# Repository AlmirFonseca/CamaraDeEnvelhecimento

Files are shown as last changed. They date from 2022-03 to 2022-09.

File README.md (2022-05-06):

# Câmara de Envelhecimento
Repositório de manutenção da câmara de envelhecimento, construído para o Dep. Eng. Civil da Universidade Federal de Viçosa.

## Módulos
A Câmara dispõe de diversos módulos, os quais estão representados nos <a href=“https://github.com/AlmirFonseca/CamaraDeEnvelhecimento/tree/main/Diagramas%20de%20montagem“>diagramas de montagem</a> e estão listados abaixo:
                
+ Arduino MEGA 2560
+ Sensor de Temperatura  DS18B20 (I e II)
+ Sensor de Umidade DHT22
+ Sensor de Irradiância UV ML8511
+ RTC DS3231
+ Módulo de Cartão Micro SD
+ Módulo de Relé (de 1 e 2 canais)
+ Rotary Encoder KY-040
+ Display LCD 16x2
+ Fonte de alimentação MB102
                
----

## Manutenção
Para a maioria dos casos de mau funcionamento da parte eletrônica da câmara, seguem as seguintes instruções:

1. Verificar se, ao incializar o dispositivo, alguma mensagem de erro é exibida no display LCD. Caso algum erro seja relatado, siga as orientações descritas na tela.
2. Confira as conexões do módulo que apresenta mau funcionamento, verificando se não há algum cabo solto no interior da caixa, ou se está apenas mal conectado
3. Para alguns casos, existem considerações especiais:
	3.1. No caso de mau funcionamento do relógio (RTC DS3231) confira as conexões caso a data seja "165/165/2165", e confira o estado da bateria (CR2032) caso a data seja algo como "01/01/2000".
	3.2. Caso ocorram erros no arquivamento dos arquivos no cartão de memória, é recomendado retirá-lo e formatá-lo o cartão com o auxílio do [SD Card Formatter](https://www.sdcard.org/downloads/formatter/), utilizando a configuração "Overwrite format" (ATENÇÃO, pois isso apagará todos os dados existentes na memória do cartão).
4. Caso nenhum dos procedimentos acima tenha surtido efeito, é recomendado avaliar a integridade do componente que apresenta mau funcionamento, seja a partir de um outro código para o Arduino, ou seja substituindo esse componente por um similar. Todos os componentes podem ser substituídos, sem serem necessárias alterações no código-fonte do Arduino.
                
----

## Conexões
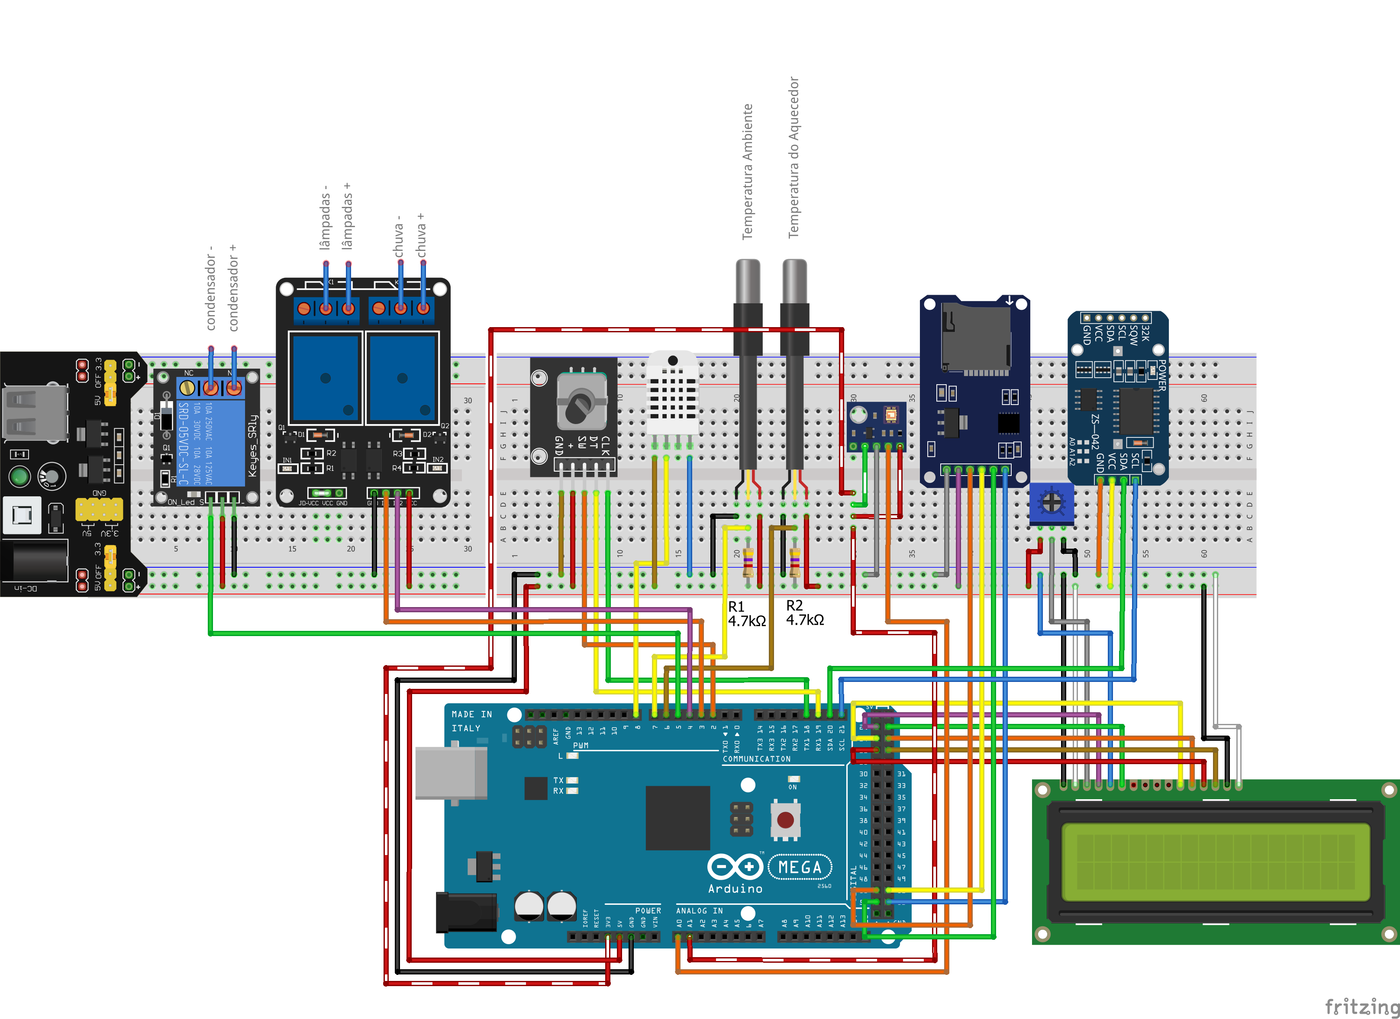
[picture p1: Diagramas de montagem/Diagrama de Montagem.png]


+ Sensor de Temperatura  DS18B20 (I e II):
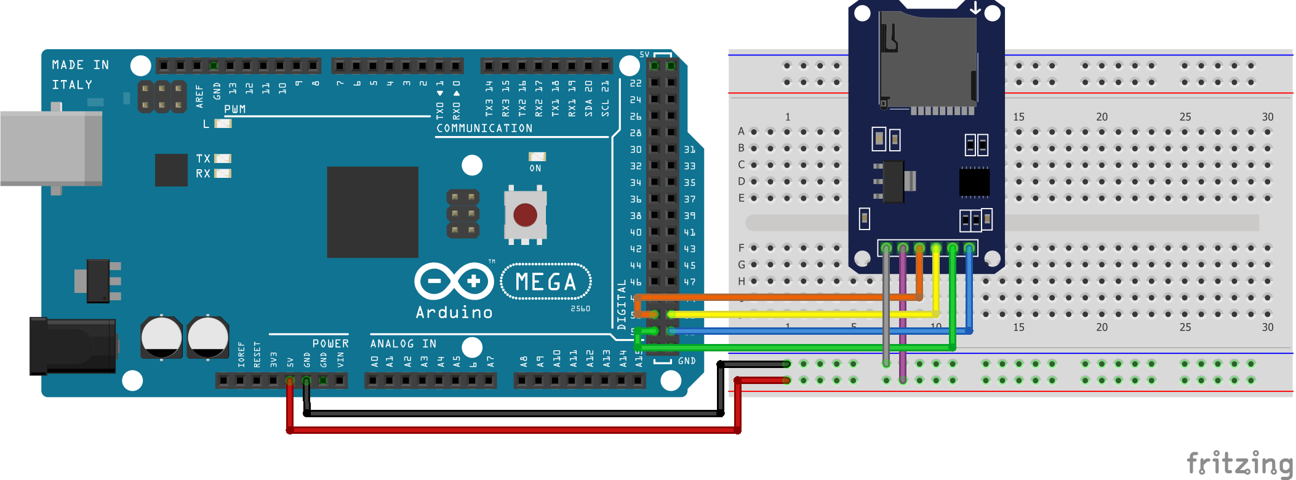
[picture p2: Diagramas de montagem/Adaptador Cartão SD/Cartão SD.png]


+ Sensor de Umidade DHT22:
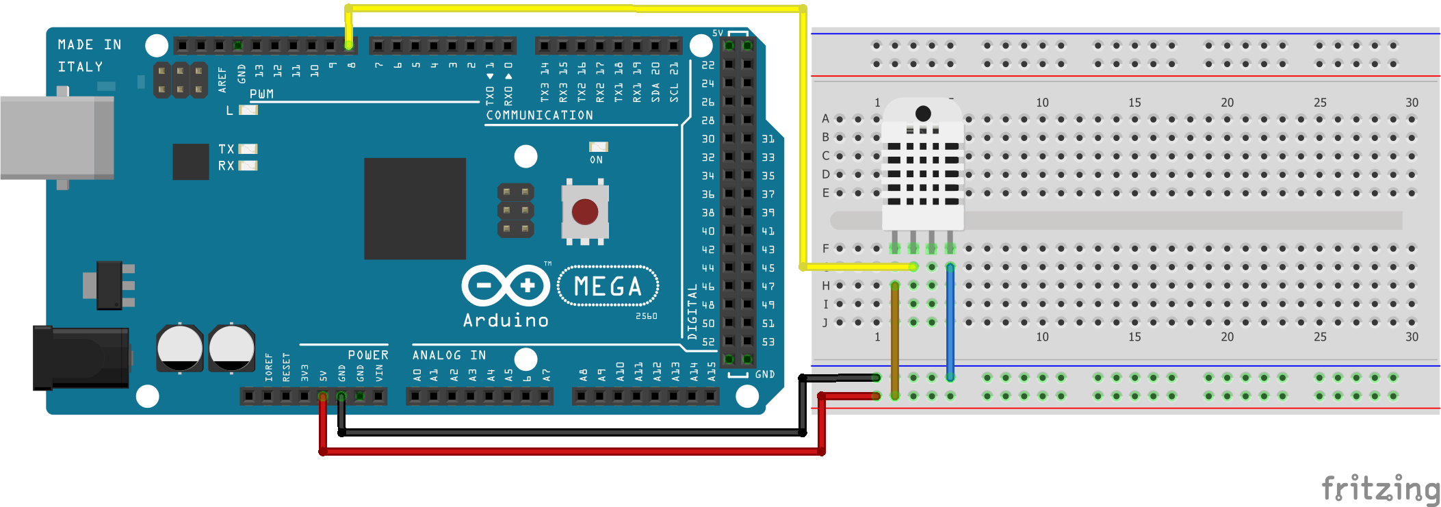
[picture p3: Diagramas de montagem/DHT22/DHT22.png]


+ Sensor de Irradiância UV ML8511:
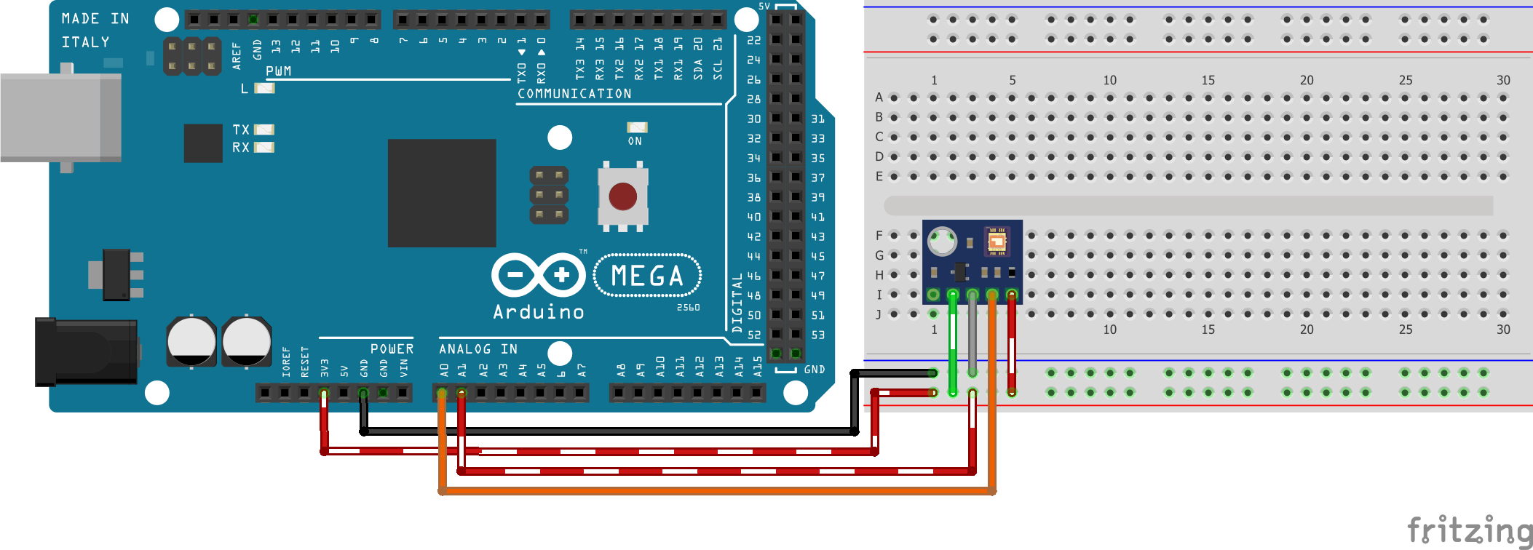
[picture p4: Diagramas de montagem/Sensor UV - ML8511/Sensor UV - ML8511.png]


+ RTC DS3231:
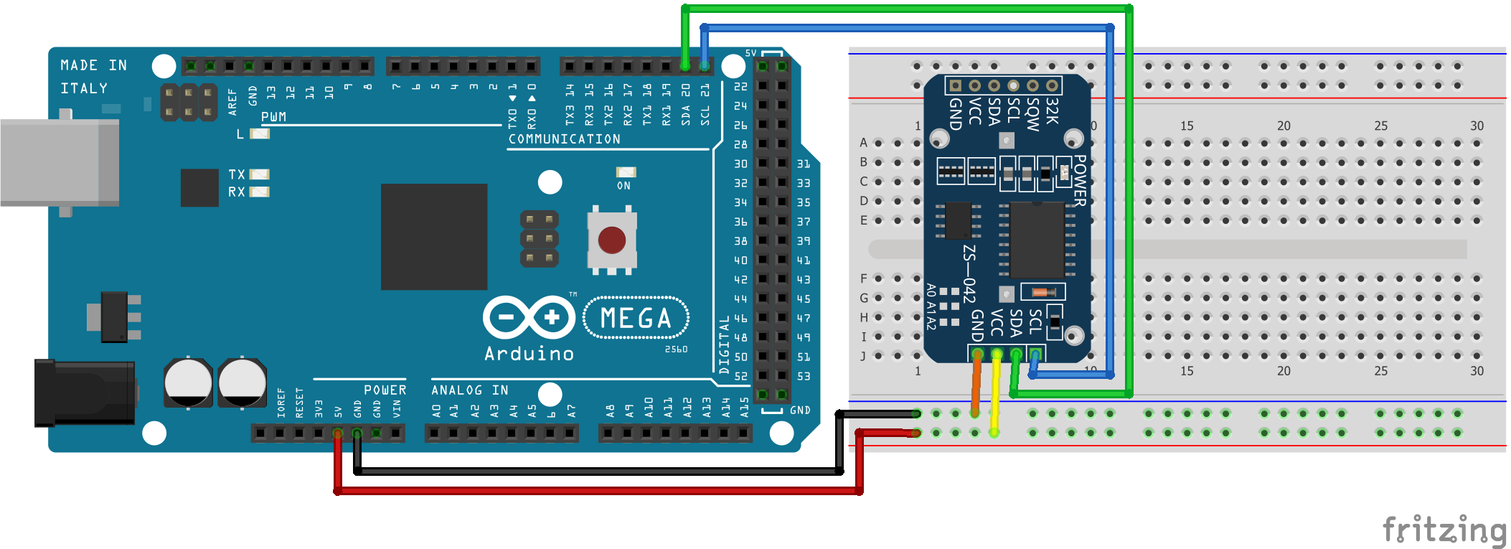
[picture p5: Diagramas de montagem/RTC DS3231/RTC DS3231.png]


+ Módulo de Cartão Micro SD:


+ Rotary Encoder KY-040:
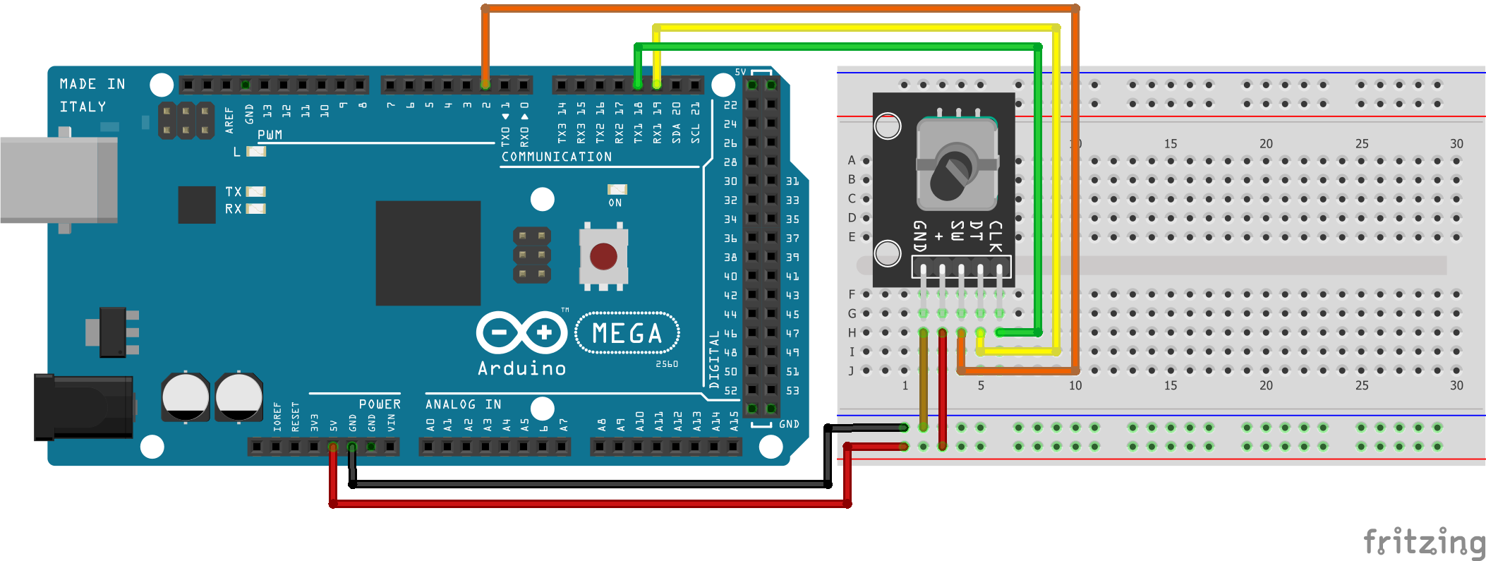
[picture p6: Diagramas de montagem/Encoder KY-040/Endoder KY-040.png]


+ Display LCD 16x2:
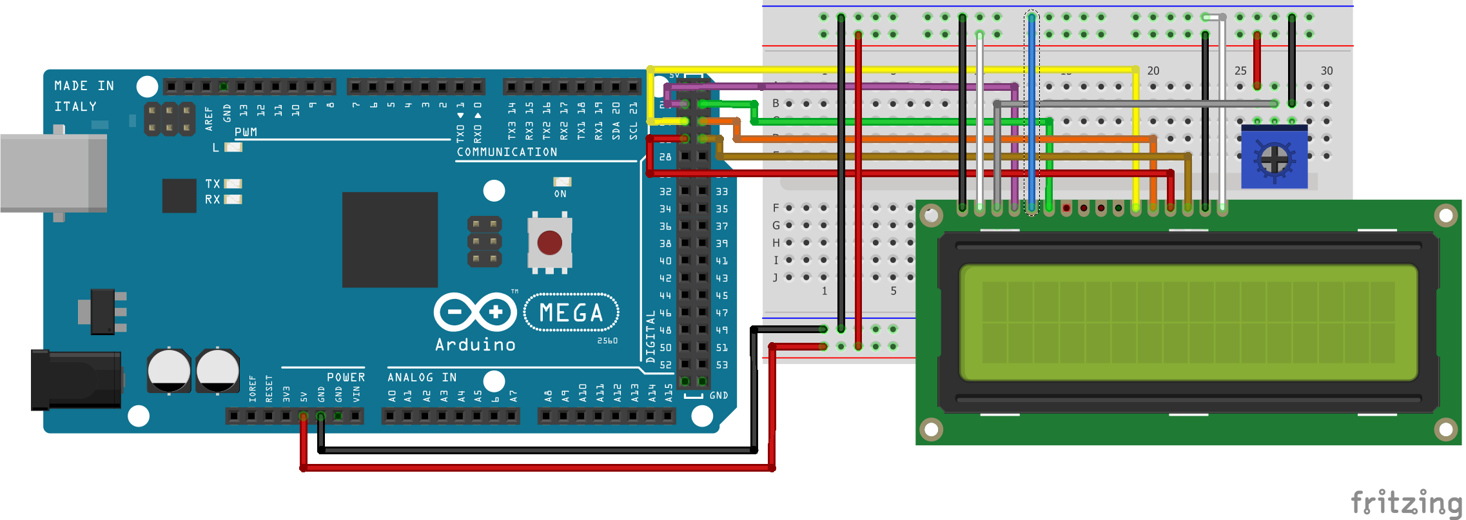
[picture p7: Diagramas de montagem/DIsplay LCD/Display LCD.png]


+ Módulo de Relé (de 1 e 2 canais):

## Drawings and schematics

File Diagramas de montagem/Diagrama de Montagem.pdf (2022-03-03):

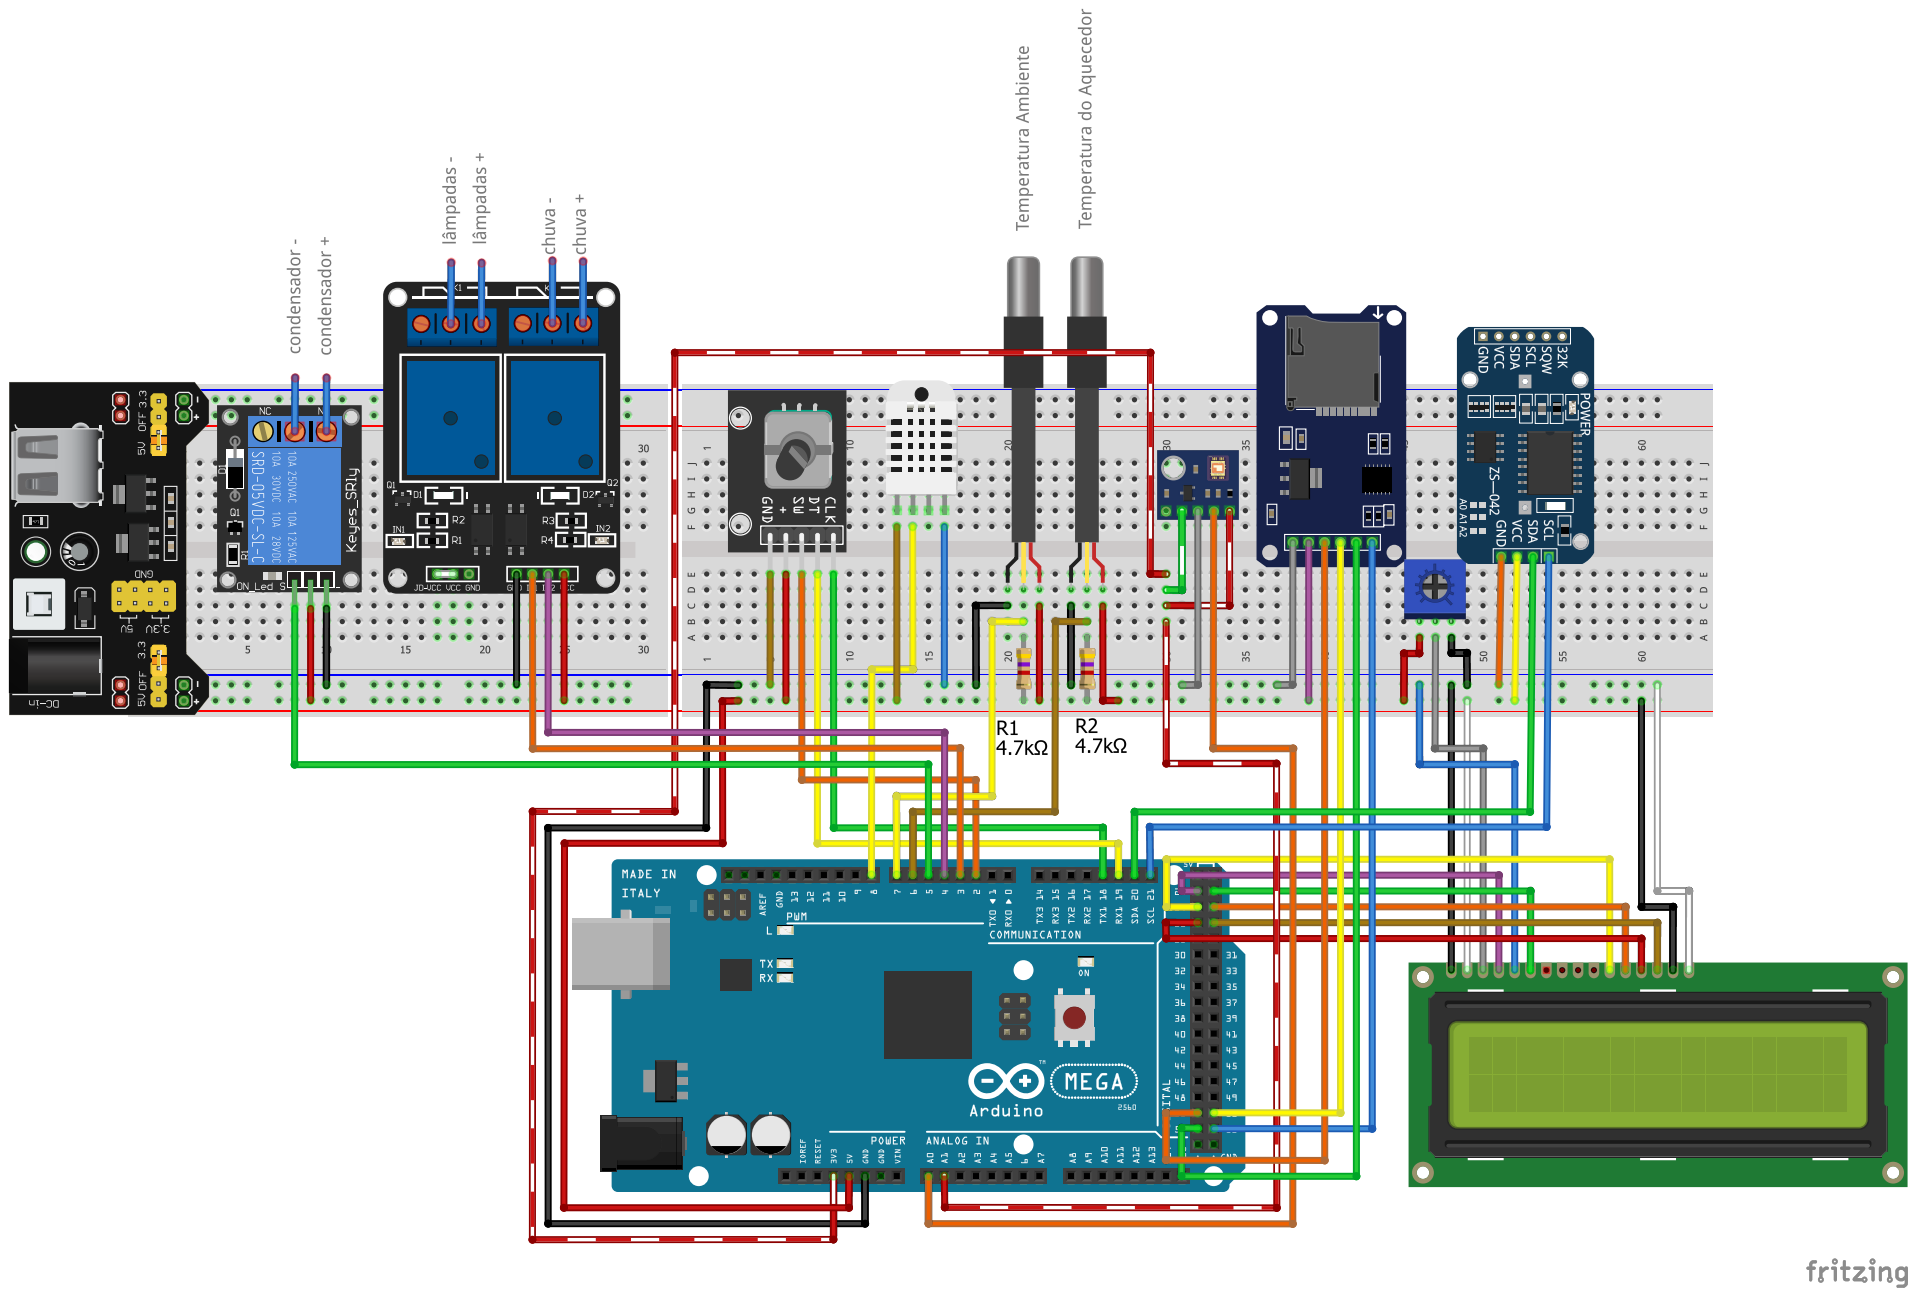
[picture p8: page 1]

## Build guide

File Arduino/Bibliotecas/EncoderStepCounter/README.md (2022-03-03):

EncoderStepCounter library
==========================

A library which can be used th increment/decrement a counter based on rotary encoder movement.

It supports full-step and half-step encoders.

For more details on how to use this library, have a look at the examples.

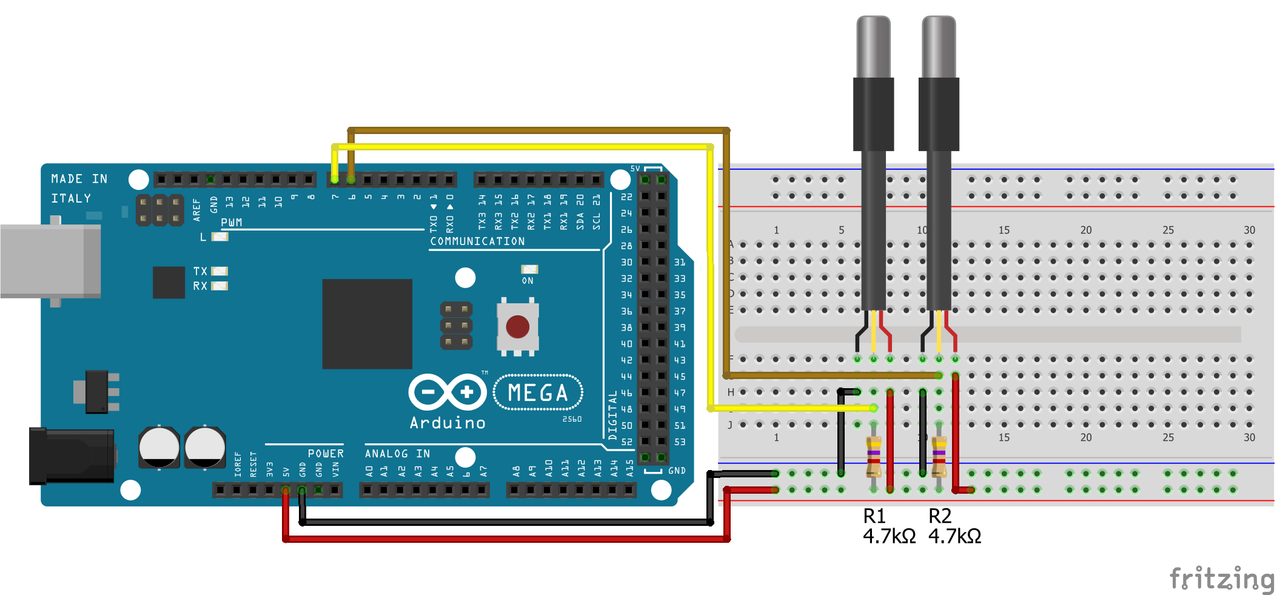
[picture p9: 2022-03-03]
Diagramas de montagem/Termômetros DS18B20/DS18B20.png

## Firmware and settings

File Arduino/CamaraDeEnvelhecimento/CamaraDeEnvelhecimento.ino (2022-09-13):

#include <DHT.h>
#include <Wire.h>
#include "RTClib.h"
#include <OneWire.h>
#include <DallasTemperature.h>
#include <LiquidCrystal_I2C.h>
#include <SPI.h>
#include <SD.h>
#include "EncoderStepCounter.h"
#include <avr/wdt.h>
#include <TimerThree.h>

#define RELAY_LUZUV 3
#define RELAY_CHUVA 4
#define RELAY_CONDENSACAO 5
bool isChuva, isLuzUV, isCondensacao; // Variáveis que contém o estado atual dos relays

// Como os relés são "low level triggered" (se ativam em LOW), os valores de ON e OFF são, respectivamente, 0 e 1
#define ON 0
#define OFF 1

#define DHTPIN 8
#define DHTTYPE DHT22 // Aponta qual é o modelo do sensor de umidade
DHT dht(DHTPIN, DHTTYPE); // Declara o sensor de umidade como um objeto "dht"

#define ML8511 A0
#define REF_3V3 A1

#define ONE_WIRE_BUS_1 6
#define ONE_WIRE_BUS_2 7

OneWire oneWire1(ONE_WIRE_BUS_1);
OneWire oneWire2(ONE_WIRE_BUS_2);

DallasTemperature sensorTemperatura1(&oneWire1);
DallasTemperature sensorTemperatura2(&oneWire2);

/*uint8_t sensorTemperatura1[8] = { 0x28, 0x27, 0xAE, 0x79, 0xA2, 0x00, 0x03, 0xDC }; // Serial number do sensor de temperatura I (do aquecedor)
uint8_t sensorTemperatura2[8] = { 0x28, 0x40, 0x8F, 0x16, 0xA8, 0x01, 0x3C, 0xF4 }; // Serial number do sensor de temperatura II (do ambiente)*/

// Configura a temperatura (em °C) mínima e máxima da água da condensação durante seu funcionamento
int tempMinAquecedor = 70;
int tempMaxAquecedor = 80;

RTC_DS3231 rtc; // Declara o RTC como um objeto "rtc"
DateTime now, dateAux;
char dateBuffer[10];
char timeBuffer[8];
char LCDTimeBuffer[5];

LiquidCrystal_I2C lcd(0x27, 16, 2); // Declara o display como um objeto chamado "lcd", de endereço I2C 0x27, x colunas e y linhas; Nesse caso, lcd(0x27, 16, 2);
byte aoQuadrado[] = {B01100,B10010,B00100,B01000,B11110,B00000,B00000,B00000};
char LCDCiclosText[6];
int dadoLCD = 0;

unsigned long int lixo = 0;
int lixo2 = 0;

// Para o cartão SD, 3 pinos são fixos
// SCK = 52;
// MISO = 50;
// MOSI = 51;
const int CS = 53; // Determina o ultimo pino
File dataFile;

// Define as variáveis relacionadas ao Rotary Encoder
#define INTERRUPT_SW_PIN 2
#define INTERRUPT_DT_PIN 19
#define INTERRUPT_CLK_PIN 18
signed long int encoderValue = 0;
signed char encoderPosition;
unsigned long int lastButtonPress = 0;
int debounceTimeMillis = 100;
int holdTimeMillis = 2000;
bool debounced = true;
int SWState;
int encoderSW = 0;
bool toMenu = false;
EncoderStepCounter encoder(INTERRUPT_CLK_PIN, INTERRUPT_DT_PIN, HALF_STEP);

// Para alterar o número máximo de ciclos, basta alterar a variável abaixo
int numeroMaxDeCiclos = 84;
// Além disso, é necessário preencher a arrays abaixo no seguinte formato: array[3][x], sendo x = (3 * numeroMaxDeCiclos) + 1
byte checkpoints[3][253] = {0};
long int checkpointsTimestamps[253] = {0};

// Define as durações padrão dos ciclos (em minutos)
int duracaoCiclos[3] = {480, 15, 225};
/*
duracaoCiclos[0] = 480; // Duração do ciclo UV: 08:00:00
duracaoCiclos[1] = 15; // Duração do ciclo de chuva: 00:15:00
duracaoCiclos[2] = 225; // Duração do ciclo de condensação: 03:45:00
*/

int tempoEntreArquivamentos = 300; // Declara o tempo, em segundos, entre cada atualização nos dados salvos nos arquivos do cartão de memória

int umidade; // Variável que armazena a umidade
float temperaturaC1, temperaturaC2;
float Vout, irradiancia;
int instrucaoAtual, totalInstrucoes;
int cicloAtual, totalCiclos;
int faseAtual;
char dataCiclo[18];
char auxCharBuffer[10];
unsigned long int previousSensorLog = 0;

unsigned long int startTime;
long int aux;
float floatAux;
long int horas, minutos, segundos;
String stringAux;
int i, j;

byte numeroDeLeituras;
int valor;

void(* resetFunc) (void) = 0;

void setup() {

  Timer3.initialize(6000000);
  Timer3.attachInterrupt(watchdog_reset);
  wdt_enable(WDTO_8S);
  
  Serial.begin(115200);

  Serial.println(F("Inicializando..."));

  pinMode(INTERRUPT_SW_PIN, INPUT_PULLUP);
  pinMode(INTERRUPT_DT_PIN, INPUT);
  pinMode(INTERRUPT_CLK_PIN, INPUT);
  
  encoder.begin();
  attachInterrupt(digitalPinToInterrupt(INTERRUPT_SW_PIN), buttonInterrupt, CHANGE);
  attachInterrupt(digitalPinToInterrupt(INTERRUPT_DT_PIN), encoderInterrupt, CHANGE);
  attachInterrupt(digitalPinToInterrupt(INTERRUPT_CLK_PIN), encoderInterrupt, CHANGE);

  lcd.init(); // Inicia o display lcd
  Serial.println(F("Display LCD ligado")); // Informa, na porta serial, que o display esta ligado
  lcd.backlight(); // Liga a luz de fundo do display
  lcd.createChar(0, aoQuadrado);

  Serial.print(F("Iniciando cartão SD... "));
  pinMode(CS, OUTPUT); // Configura o pino CS (Chip Select) como saída
    
  if(SD.begin(CS)){ // Caso a inicialização do SD no pino CS ocorra com sucesso
    Serial.println(F("Cartão SD inicializado corretamente")); // Imprime uma mensagem de sucesso
  }else{ // Caso a inicialização do SD no pino CS falhe
    Serial.println(F("Falha na inicialização do cartão SD")); // Imprime uma mensagem de erro

    Serial.println(F("Confira as conexões com o cartão SD, e depois aperte o botão para reiniciar a placa Arduino."));

    lcd.clear();

    encoderSW = 0;
    while(encoderSW == 0){ //Inicia um loop, pois o cartão não foi devidamente iniciado. Ao pressionar o botão, o Arduino reiniciará.
      lcd.setCursor(0, 0);
      lcd.print("Erro ao iniciar:");
      lcd.setCursor(0, 1);
      lcd.print("Cartao SD");
    }
    
    resetFunc();
  }
  
  // Inicialização do RTC DS3231
  if(!rtc.begin()){ // Se ocorrer um erro na inicialização do RTC DS3231
    Serial.println(F("Não foi possível reconhecer o RTC! Verifique as conexões"));

    crashLog(F("Erro ao inicializar o RTC (Real Time CLock)"));

    lcd.clear();

    encoderSW = 0;
    while(encoderSW == 0){
      lcd.setCursor(0, 0);
      lcd.print("Erro ao iniciar:");
      lcd.setCursor(0, 1);
      lcd.print("RTC DS3231");
    }
    resetFunc();
    
  }else{
    Serial.println(F("RTC DS3231 inicializado corretamente"));
  }
  now = rtc.now();
  stringAux = parseDate(now);
  if(stringAux == "165/165/2165"){
    Serial.println(F("Data incorreta!"));
    Serial.println(parseDate(now)+" "+parseTime(now)); // Imprime o horário atual

    crashLog(F("RTC com data incorreta (165/165/2165) - erro nas conexões com o RTC"));

    lcd.clear();
    encoderSW = 0;
    while(encoderSW == 0){
      lcd.setCursor(0, 0);
      lcd.print("Data incorreta!");
      lcd.setCursor(0, 1);
      lcd.print(parseDate(now)); // Imprime o horário atual
    }

    Serial.println(F("Confira as conexões do RTC DS3231"));
    lcd.clear();
    encoderSW = 0;
    while(encoderSW == 0){
      lcd.setCursor(0, 0);
      lcd.print("Confira as");
      lcd.setCursor(0, 1);
      lcd.print("conexoes do RTC");
    }
    
    Serial.println(F("Pressione novamente para reiniciar o dispositivo"));
    lcd.clear();
    encoderSW = 0;
    while(encoderSW == 0){
      lcd.setCursor(0, 0);
      lcd.print("Pressione novam.");
      lcd.setCursor(0, 1);
      lcd.print("para reiniciar");
    }
    
    resetFunc();
  //}else if(stringAux == "01/01/2000"){
  }else if(now.year() == 2000){
    Serial.println(F("Data incorreta!"));
    Serial.println(parseDate(now)+" "+parseTime(now)); // Imprime o horário atual

    crashLog(F("RTC com data incorreta - sem bateria"));

    lcd.clear();
    encoderSW = 0;
    while(encoderSW == 0){
      lcd.setCursor(0, 0);
      lcd.print("Data incorreta!");
      lcd.setCursor(0, 1);
      lcd.print(parseDate(now)); // Imprime o horário atual
    }

    Serial.println(F("Confira a bateria do RTC DS3231"));
    lcd.clear();
    encoderSW = 0;
    while(encoderSW == 0){
      lcd.setCursor(0, 0);
      lcd.print("Confira a");
      lcd.setCursor(0, 1);
      lcd.print("bateria do RTC");
    }
    
    Serial.println(F("Substituia a bateria do RTC e pressione novamente para ajustar o horário"));
    lcd.clear();
    encoderSW = 0;
    while(encoderSW == 0){
      lcd.setCursor(0, 0);
      lcd.print("Pressione novam.");
      lcd.setCursor(0, 1);
      lcd.print("p/ ajustar o RTC");
    }
    
    dateAux = rtc.now();
    ajustarHorario(dateAux);
  }


  Serial.print(F("Hora atual: "));
  Serial.print(parseDate(now));
  Serial.print(F(" "));
  Serial.println(parseTime(now)); // Imprime o horário atual

  dataFile = SD.open("boot.csv", FILE_WRITE);

  if(dataFile){
    dataFile.println(parseDate(now)+" "+parseTime(now));
  }else{
    Serial.println(F("Erro ao abrir boot.csv"));

    lcd.clear();
    encoderSW = 0;
    while(encoderSW == 0){
      lcd.setCursor(0, 0);
      lcd.print("Erro ao abrir:");
      lcd.setCursor(0, 1);
      lcd.print("boot.csv");
    }
    resetFunc();
  }

  dataFile.close();

  Serial.println();

  // Inicialização dos relays
  pinMode(RELAY_CHUVA, OUTPUT); // Declara o pino RELAY_CHUVA como OUTPUT
  pinMode(RELAY_LUZUV, OUTPUT); // Declara o pino RELAY_LUZUV como OUTPUT
  pinMode(RELAY_CONDENSACAO, OUTPUT); // Declara o pino RELAY_CONDENSACAO como OUTPUT
  chuva(false); // Desliga a bomba de água
  luzUV(false); // Desliga as lâmpadas UV
  condensacao(false); // Desliga o aquecedor de água

  // Inicialização do Sensor de Umidade
  dht.begin();
  Serial.println(F("Sensor de umidade DHT22 inicializado corretamente"));

  // Inicialização do Sensor de luz UV

  pinMode(ML8511, INPUT);
  pinMode(REF_3V3, INPUT);

  // Inicialização dos Sensores de Temperatura
  sensorTemperatura1.begin();
  sensorTemperatura2.begin();

  Serial.print(F("Localizando termômetros... "));
  Serial.print(F("Foram encontrados "));
  aux = sensorTemperatura1.getDeviceCount() + sensorTemperatura2.getDeviceCount();
  Serial.print(aux, DEC);
  Serial.println(F(" sensores DS18B20"));

  sensorTemperatura1.requestTemperatures();
  delay(50);
  sensorTemperatura2.requestTemperatures();
  delay(50);

  temperaturaC1 = sensorTemperatura1.getTempCByIndex(0);
  temperaturaC2 = sensorTemperatura2.getTempCByIndex(0);
  Serial.print(F("Temperatura 1: "));
  Serial.print((String)temperaturaC1);
  Serial.println(F(" °C"));
  Serial.print(F("Temperatura 2: "));
  Serial.print((String)temperaturaC2);
  Serial.println(F(" °C"));

  if(temperaturaC1 == -127.00 || temperaturaC2 == -127.00){
    Serial.println(F("Algum termômetro não está funcionando corretamente"));
    Serial.println(F("Confira as conexões e tente novamente"));

    crashLog(F("Erro ao inicializar o(s) termometro(s)"));
    
    lcd.clear();
    encoderSW = 0;
    while(encoderSW == 0){
      lcd.setCursor(0, 0);
      lcd.print("Erro ao utilizar:");
      lcd.setCursor(0, 1);
      lcd.print("Termometros");
    }

    lcd.clear();
    encoderSW = 0;
    while(encoderSW == 0){
      lcd.setCursor(0, 0);
      lcd.print("Temperatura 1:");
      lcd.setCursor(0, 1);
      lcd.print(temperaturaC1);
      if(temperaturaC1 == -127.00){
        lcd.print(" (ERRO)");
      }                                                 
    }

    lcd.clear();
    encoderSW = 0;
    while(encoderSW == 0){
      lcd.setCursor(0, 0);
      lcd.print("Temperatura 2:");
      lcd.setCursor(0, 1);
      lcd.print(temperaturaC2);
      if(temperaturaC2 == -127.00){
        lcd.print(" (ERRO)");
      }                                                
    }
    
    Serial.println(F("Pressione novamente para reiniciar o dispositivo"));
    lcd.clear();
    encoderSW = 0;
    while(encoderSW == 0){
      lcd.setCursor(0, 0);
      lcd.print("Pressione novam.");
      lcd.setCursor(0, 1);
      lcd.print("para reiniciar");
    }
    
    resetFunc();
  }

  Serial.println(F("Inicialização realizada com sucesso!"));
  Serial.println();
  delay(100);

  if(SD.exists("data.txt")){
  //if(1 == 0){ ///////////// TESTE
    Serial.println(F("Rotina em andamento encontrada. Iniciando retomada..."));
    continuarRotina();
  }else{
    Serial.println(F("Nenhuma rotina em andamento foi encontrada. Iniciando uma nova rotina..."));
    novaRotina();
  }
}

void loop() {

  now = rtc.now();

  stringAux = parseDate(now);
  if(stringAux == "165/165/2165" || stringAux == "01/01/2000"){
    Serial.println(F("Data incorreta!"));
    Serial.println(parseDate(now)+" "+parseTime(now)); // Imprime o horário atual

    resetFunc();
  }

  Serial.println(parseDate(now)+" "+parseTime(now));

  // Verificar se é necessário atualizar o ciclo e o estado atual dos relays
  if(now.unixtime() >= checkpointsTimestamps[instrucaoAtual]){
  //if(1 == 1){
    Serial.println(F("Atualizando ciclo..."));
    atualizarCiclo(now, totalInstrucoes);
  }else{ // Caso contrário, é executada uma rotina de obtenção e log de dados dos sensores
    
    ///////////////////////////////////////////////////////////////////////////////////////// DEBUG
    Serial.print(F("Ciclo e fase atual: "));
    Serial.println((String)cicloAtual+" - "+(String)faseAtual);
    
    /*Serial.print(F("Instrução atual: "));
    Serial.println((String)instrucaoAtual);
    
    Serial.print(F("checkpoints[2][instrucaoAtual] = "));
    Serial.println((String)checkpoints[2][instrucaoAtual]);*/

    // Exibe o horário atual no Display LCD
    lcd.setCursor(0, 0); // Posiciona o cursor na primeira coluna (0) e na primeira linha (0)
    lcd.print(parseLCDTime(now)); // Imprime, na primeira linha, o horário (HH:MM)

    // Exibe o ciclo atual, a fase atual e o total de ciclos no Display LCD
    sprintf(LCDCiclosText, "C%03d-%01d/%03d", cicloAtual, faseAtual, totalCiclos);
    lcd.setCursor(6, 0);
    lcd.print(LCDCiclosText);

    // get humidity
    umidade = dht.readHumidity();
    Serial.print(F("Umidade: "));
    Serial.print((String)umidade);
    Serial.println(F(" %HR"));

    // get temperature(s)
    sensorTemperatura1.requestTemperatures();
    delay(50);
    sensorTemperatura2.requestTemperatures(); 
    delay(50);

    temperaturaC1 = sensorTemperatura1.getTempCByIndex(0);
    temperaturaC2 = sensorTemperatura2.getTempCByIndex(0);
    Serial.print(F("Temperatura 1: "));
    Serial.print((String)temperaturaC1);
    Serial.println(F(" °C"));
    Serial.print(F("Temperatura 2: "));
    Serial.print((String)temperaturaC2);
    Serial.println(F(" °C"));

    if(temperaturaC1 == -127.00 || temperaturaC2 == -127.00){
      Serial.println(F("Algum termômetro não está funcionando corretamente"));
      Serial.println(F("Reiniciando para tentar resolver o problema..."));
      resetFunc();
    }

    if(faseAtual == 3){
      if(temperaturaC1 >= tempMaxAquecedor){
        if(isCondensacao){
          Serial.print(F("Temperatura acima de 80 °C - Desligando o Aquecedor..."));
          condensacao(false);
        }
      }else if(temperaturaC1 <= tempMinAquecedor){
        if(!isCondensacao){
          Serial.print(F("Temperatura abaixo de 70 °C - Ligando o Aquecedor..."));
          condensacao(true);
        }
      }
    }

    // get UV
    Vout = 3.3 / mediaAnalogica(REF_3V3) * mediaAnalogica(ML8511);
    irradiancia = mapFloat(Vout, 0.99, 2.8, 0.0, 150.0);
    Serial.print(F("Irradiância: "));
    Serial.print((String)irradiancia);
    Serial.println(F(" W/m²"));

    // Exiibe dados dos sensores no Display LCD
    lcd.setCursor(0, 1);
    lcd.print("                ");
    lcd.setCursor(0, 1);

    if(dadoLCD == 4){
      dadoLCD = 0;
    }

    /*Serial.print(F("dadoLCD (1): "));
    Serial.println(dadoLCD);*/

    if(dadoLCD == 0){
      lcd.print("Umidade: "+(String)umidade+" %HR");
    }else if(dadoLCD == 1){
      lcd.print("Temp1: "+(String)temperaturaC1+(String)char(223)+"C");
    }else if(dadoLCD == 2){
      lcd.print("Temp2: "+(String)temperaturaC2+(String)char(223)+"C");
    }else if(dadoLCD == 3){
      lcd.print("Irr.: ");
      lcd.print((String)irradiancia);
      lcd.print(" W/m");
      lcd.write(byte(0));
    }
    dadoLCD++;

    /*Serial.print(F("dadoLCD (2): "));
    Serial.println(dadoLCD);*/

    //if(1){
    if(now.unixtime() - previousSensorLog >= tempoEntreArquivamentos){

      Serial.println(F("Arquivando dados..."));
      
      //Serial.print(F("previousSensorLog: "));
      //Serial.print(previousSensorLog);
      //Serial.print(F(" -> "));
      previousSensorLog = now.unixtime();
      //Serial.println(previousSensorLog);
      
      // Armazena os dados dos sensores no cartão (sensores.csv)
      dataFile = SD.open("sensores.csv", FILE_WRITE);
      
      if(dataFile){
        dataFile.print(parseDate(now));
        dataFile.print(F(" "));
        dataFile.print(parseTime(now));
        dataFile.print(F(";"));
        dataFile.print(cicloAtual);
        dataFile.print(F(";"));
        dataFile.print(faseAtual);
        dataFile.print(F(";"));
        dataFile.print(umidade);
        dataFile.print(F(";"));
        dataFile.print(temperaturaC1);
        dataFile.print(F(";"));
        dataFile.print(temperaturaC2);
        dataFile.print(F(";"));
        dataFile.println((String)irradiancia);

      }else{
        Serial.println(F("Erro ao abrir sensores.csv"));

        crashLog(F("Erro ao abrir sensores.csv"));

        lcd.clear();
        encoderSW = 0;
        while(encoderSW == 0){
          lcd.setCursor(0, 0);
          lcd.print("Erro ao abrir:");
          lcd.setCursor(0, 1);
          lcd.print("sensores.csv");
        }
        resetFunc();
      }

      dataFile.close();

      dataFile = SD.open("freeram.csv", FILE_WRITE);

      if(dataFile){
        dataFile.print(parseDate(now));
        dataFile.print(F(" "));
        dataFile.print(parseTime(now));
        dataFile.print(F(";"));
        dataFile.println(freeMemory());
      }else{
        Serial.println(F("Erro ao abrir freeram.csv"));
  
        crashLog(F("Erro ao abrir freeram.csv"));
  
        lcd.clear();
        encoderSW = 0;
        while(encoderSW == 0){
          lcd.setCursor(0, 0);
          lcd.print("Erro ao abrir:");
          lcd.setCursor(0, 1);
          lcd.print("freeram.csv");
        }
        resetFunc();
      }
  
      dataFile.close();
    }

    //Serial.print(F("lixo (1): "));
    //Serial.println(lixo);
    lixo++;
    //Serial.print(F("lixo (2): "));
    //Serial.println(lixo);

    //Serial.print(F("lixo2 (1): "));
    //Serial.println(lixo2);
    lixo2++;
    //Serial.print(F("lixo2 (2): "));
    //Serial.println(lixo2);

    Serial.print(F("RAM disponível: "));
    Serial.println(freeMemory());
    Serial.println();

    // Delay de 10 seg
    aux = millis();
    while(millis() - aux < 10000){
      if(toMenu){
        // Abre o Menu
        toMenu = false;
        encoderSW = 0;
        menu(totalInstrucoes);
      }
    }
  }
}

#ifdef __arm__
// should use uinstd.h to define sbrk but Due causes a conflict
extern "C" char* sbrk(int incr);
#else // __ARM__
extern char *__brkval;
#endif // __arm__
int freeMemory() {
  char top;
  #ifdef __arm__
  return &top - reinterpret_cast<char*>(sbrk(0));
  #elif defined(CORE_TEENSY) || (ARDUINO > 103 && ARDUINO != 151)
  return &top - __brkval;
  #else // __arm__
  return __brkval ? &top - __brkval : &top - __malloc_heap_start;
  #endif // __arm__
}

void watchdog_reset(){
  wdt_reset();
}

void buttonInterrupt(){
  SWState = digitalRead(INTERRUPT_SW_PIN);

  // Indica um RAISING
  if(SWState){
    // Se o pressionamento do botão for válido
    if(debounced){
      debounced = false;
      // Indica um LONG PRESS
      if(millis() - lastButtonPress >= holdTimeMillis){
        toMenu = true;
        encoderSW = 1;
      // Indica um SHORT PRESS
      }else{
        toMenu = false;
        encoderSW = 1;
      }
      lastButtonPress = millis();
    }else{
      // Se o pressionamento do botão for inválido
    }
  // Indica um FALLING
  }else{
    // Indica um debounce = true
    if(millis() - lastButtonPress >= debounceTimeMillis){
      debounced = true;
      lastButtonPress = millis();
    // Indica um debounce = false
    }else{
      debounced = false;
    }   
  }
}

void encoderInterrupt(){
  encoder.tick();

  encoderPosition = encoder.getPosition();
    if (encoderPosition != 0) {
      encoderValue += encoderPosition;
      encoder.reset();
    }
}

void crashLog(String errorMessage){
  dateAux = rtc.now();

  dataFile = SD.open("crashlog.csv", FILE_WRITE);

  if(dataFile){
    dataFile.print(parseDate(dateAux)+" "+parseTime(dateAux));
    dataFile.print(F(";"));
    dataFile.println(errorMessage);

    dataFile.close();
  }else{
    Serial.println(F("Erro ao abrir crashlog.csv"));

    /*lcd.clear();
    encoderSW = 0;
    while(encoderSW == 0){
      lcd.setCursor(0, 0);
      lcd.print(F("Erro ao abrir:"));
      lcd.setCursor(0, 1);
      lcd.print("crashlog.csv");
    }
    resetFunc();*/
  }
}
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

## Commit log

2022-03-03 Diagrama de montagem geral
2022-07-14 Corrija o bug visual do menu, e adicione um delay´após cada atualização de ciclo
    [CamaraDeEnvelhecimento.ino]
2022-07-15 Adicione feature de teste de equipamentos
2022-08-13 Aprimore o sistema para low level triggered relays, altere o LCD para operar a partir do I2C, e corrija alguns bugs
    [CamaraDeEnvelhecimento.ino]
2022-09-08 Defina variáveis globais para controlar a duração de cada ciclo (em minutos)
2022-09-08 Altere o armazenamento das durações dos ciclos para uma lista, permitindo a sua iteração
2022-09-10 Abra o menu apenas através de um long press (2 seg)
2022-09-13 Permita a edição da duração de cada ciclo
    Cada ciclo possui um valor padrão (485, 12 e 225 minutos, respectivamente) e que pode ser alterado ao iniciar uma nova rotina. Essa alteração é válida apenas para rotina atual e permite selecionar um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
